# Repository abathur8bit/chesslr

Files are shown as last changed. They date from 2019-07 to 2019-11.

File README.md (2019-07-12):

# ChessLR
Electronic chess board project <https://www.8bitcoder.com/chesslr>

ChessLR is will be an chess e-Board and Chess Computer that can sense and record the movement of chess pieces. 

# Features

- Record games between two players.
- Play against a computer, and record the game.
- Recorded games can be downloaded. 
- Moves by the computer are indicated on the board using LEDs.
- Shows when you make a move that isn't legal.
- Setup any board position.

# How it works
There will be sensors under the board, as well as on the pieces. In the current design, reed switches will be under each square and magnets under the pieces. Reed switches are sensitive to magnetic fields that the magnets generate, and will activate when a piece is over it. This doesn't allow for piece identification, so it doens't know if a knight or a queen is over the square. By using a little bit of clever software, it should be fairly easy to keep track of what piece is where, and what piece moved. 

# Hardware
As the project evolves, the schematics will be updated. At present the board will be utilizing:

- Raspberry Pi for control logic and chess engine.
- LEDs for each square.
- Reed switches to sense pieces.
- Magnets under the pieces.
- MCP23017 I2C port expander to allow 64 inputs, and 64 outputs.

# Software
The driver for the board will be written in Java and meant to be run on a Raspberry Pi. It will utilize read reed switch state information, turn LEDs on and off, and talk with the chess engine. Software will also need to implement chess game logic, such as if a move is legal. I was surprised to learn that a chess engine doesn't acutally do that.

[Stockfish](https://stockfishchess.org) is the chess engine of choise. It's an open source chess engine written in C. It communicates via the Universal Chess Interface (UCI). ChessLR will send moves to Stockfish and when Stockfish sends it move back, the move will be indicated on the chess board via the LEDs.

# Resources
[PI4J](https://pi4j.com/1.2/index.html) Java I/O library for Raspberry PI.

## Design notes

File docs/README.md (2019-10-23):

Contains any reference material used for the project. This includes anything related to ChessLR game or electronics of the board itself. 

# FEN, PGN, EAN
https://en.wikipedia.org/wiki/Algebraic_notation_(chess)
https://en.wikipedia.org/wiki/Portable_Game_Notation

# Maven repository JitPack
<https://jitpack.io/private#subscribe>

Createa a maven repository based on github release.

# ChessLib
What I was trying to do with ChessBoard <https://github.com/bhlangonijr/chesslib>

# Board
```
   a  b  c  d  e  f  g  h
8  00 01 02 03 04 05 06 07  8
7  08 09 10 11 12 13 14 15  7
6  16 17 18 19 20 21 22 23  6
5  24 25 26 27 28 29 30 31  5
4  32 33 34 35 36 37 38 39  4 
3  40 41 42 43 44 45 46 47  3 
2  48 49 50 51 52 53 54 55  2 
1  56 57 58 59 60 61 62 63  1
   a  b  c  d  e  f  g  h
```

# Wait for move logic table
Table shows how many pieces are expected to be picked up and put down for each situation. This handles computer moves,
takebacks, and captures.

```
TAKEBACK    CAPTURE     UP  DOWN
Y           Y           1   2
Y           N           1   1
N           Y           2   1
N           N           1   1
```
  
# Wiring Notes #

Long headers are good to have something plugin at top, and do a bunch of wire wrapping on the bottom.

Each row from chess board will have 1 blue wire, the rest grey, to show direction it should face. Perhaps a blue wire for the first reed and a blue for the first LED.

# Running remotely

lee@titan: $ ssh pi@botfly
pi@fireant:~ $ cd chesslr
pi@fireant:~/chesslr $ export DISPLAY=:0
pi@fireant:~/chesslr $ java -cp chesslr-A.1-jar-with-dependencies.jar com.axorion.chesslr.ChessLR

# USB-C
USB-C Breakout board <https://www.adafruit.com/product/4090>
USB Micro B <https://www.adafruit.com/product/1833>

USB-C <http://ww1.microchip.com/downloads/en/appnotes/00001953a.pdf>
https://electronics.stackexchange.com/questions/323128/wiring-diagram-for-usb-c-to-usb-a-cable

# MCP23017

Pin layout

```
          +----- -----+
GPB0 <--> |*1   -   28| <--> GPA7
GPB1 <--> |2        27| <--> GPA6
GPB2 <--> |3        26| <--> GPA5
GPB3 <--> |4    M   25| <--> GPA4
GPB4 <--> |5    C   24| <--> GPA3
GPB5 <--> |6    P   23| <--> GPA2
GPB6 <--> |7    2   22| <--> GPA1
GPB7 <--> |8    3   21| <--> GPA0
 VDD ---> |9    0   20| ---> INTA
 VSS ---> |10   1   19| ---> INTB
  NC ---- |11   7   18| ---> RESET
 SCL ---> |12       17| <--- A2
 SDA <--> |13       16| <--- A1
  NC ---- |14       15| <--- A0
          +-----------+
```

# Misc
Restart X windows:

    sudo systemctl restart display-manager
    
Autorun script when X starts:

Putting following in `$HOME/.config/autostart/.desktop` and set `chmod +x`:

    [Desktop Entry]
    Type=Application
    Exec="/home/pi/bin/rot.sh"
    Hidden=false
    NoDisplay=false
    X-GNOME-Autostart-enabled=true
    Name=Startup Script 

# Power consumption
Display pulls between 450 and 470mA.
Typically, the model B uses between 700-1000mA
PI Hardware details <https://www.raspberrypi.org/documentation/hardware/raspberrypi/README.md>

# Display off
xset dpms force off

# Display rotation
Normal rotation is power cord at the bottom when it is plugged into the display board.

    pi@fireant:~ $ sudo apt-get install xinput
    pi@fireant:~ $ xinput --list
    ⎡ Virtual core pointer                    	id=2	[master pointer  (3)]
    ⎜   ↳ Virtual core XTEST pointer              	id=4	[slave  pointer  (2)]
    ⎜   ↳   Mini Keyboard                         	id=7	[slave  pointer  (2)]
    ⎜   ↳ FT5406 memory based driver              	id=8	[slave  pointer  (2)]
    ⎣ Virtual core keyboard                   	id=3	[master keyboard (2)]
        ↳ Virtual core XTEST keyboard             	id=5	[slave  keyboard (3)]
        ↳   Mini Keyboard                         	id=6	[slave  keyboard (3)]

## Fireant 90 degree rotation 
Power cord will be on the right side
 
    sudo vim /boot/config.txt

Add to top 

    display_rotate=1

Then run the following. `export` is only needed if you are ssh'ed in:

    export DISPLAY=:0
    xinput set-prop 'FT5406 memory based driver' 'Evdev Axes Swap' 1
    xinput --set-prop 'FT5406 memory based driver' 'Evdev Axis Inversion' 0 1
    
## Fireant 270 degree rotation
Power cord will be on the left side

    sudo vim /boot/config.txt

Add to top

    display_rotate=3

Then run the following. `export` is only needed if you are ssh'ed in:

    export DISPLAY=:0
    xinput set-prop 'FT5406 memory based driver' 'Evdev Axes Swap' 1
    xinput --set-prop 'FT5406 memory based driver' 'Evdev Axis Inversion' 1 0

## Other docs
<https://www.raspberrypi.org/documentation/hardware/display/>

Doesn't work on older Raspbain.

display_lcd_rotate=x, where x can be one of the folllowing:

    0	no rotation
    1	rotate 90 degrees clockwise
    2	rotate 180 degrees clockwise
    3	rotate 270 degrees clockwise
    0x10000	horizontal flip
    0x20000	vertical flip

    display_rotate=0 Normal
    display_rotate=1 90 degrees (power at right)
    display_rotate=2 180 degrees
    NOTE: You can rotate both the image and touch interface 180º by entering lcd_rotate=2 instead
    display_rotate=3 270 degrees
    display_rotate=0x10000 horizontal flip
    display_rotate=0x20000 vertical flip

## Older version of Raspbian (fireant)
lcd_rotate only works with 0 and 2. 2 is flipped 180 degrees (power at the top).

If you have the lcd_rotate=2 the power cord is at the top of the display. If you don't have it, the power cord is at the bottom of the display.

No present   power cord is at bottom
lcd_rotate=0 power cord is at bottom
lcd_rotate=1 power cord is at bottom
lcd_rotate=2 power cord is at top
lcd_rotate=3 power cord is at bottom

    sudo vim /boot/config.txt
    
    # screen totation added by me
    #lcd_rotate=2
    #display_rotate=1

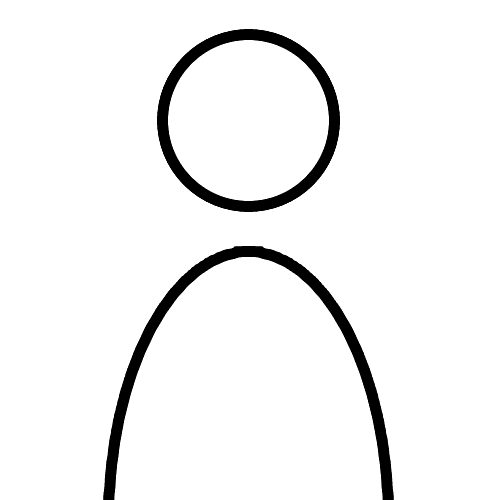
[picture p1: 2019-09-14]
src/main/java/img/button-onePlayerWhite.png

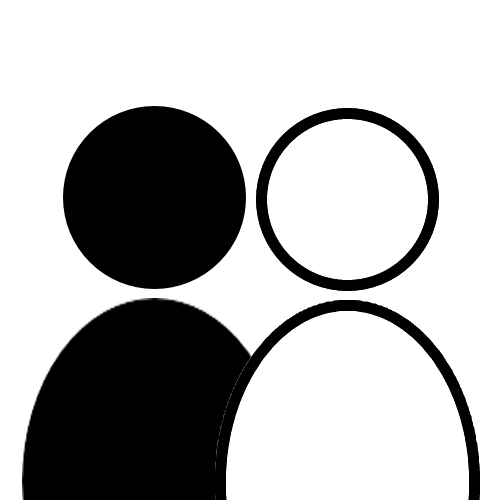
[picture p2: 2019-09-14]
src/main/java/img/button-twoPlayer.png

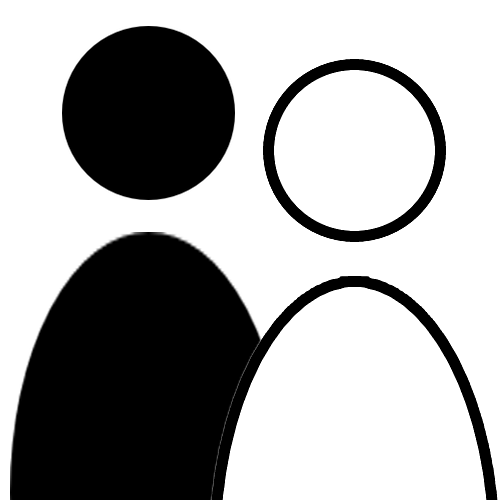
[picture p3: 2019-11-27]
src/main/java/img/button-twoPlayerWhite.png

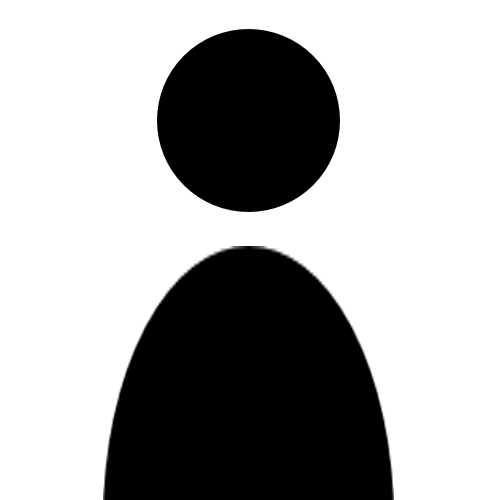
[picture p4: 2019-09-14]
src/main/java/img/button-onePlayerBlack.png

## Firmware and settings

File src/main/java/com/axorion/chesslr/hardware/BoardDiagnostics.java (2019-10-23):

package com.axorion.chesslr.hardware;

import com.axorion.chess.ChessBoard;
import com.pi4j.gpio.extension.mcp.MCP23017GpioProvider;
import com.pi4j.gpio.extension.mcp.MCP23017Pin;
import com.pi4j.io.gpio.*;
import com.pi4j.io.gpio.event.GpioPinListenerDigital;
import com.pi4j.io.i2c.I2CBus;
import com.pi4j.io.i2c.I2CFactory;

import java.io.IOException;

public class BoardDiagnostics implements PieceListener {
    class RowProvider {
        int bus,address;
        MCP23017GpioProvider gpioProvider;
        GpioPinDigitalOutput[] outputPins;
        GpioPinDigitalInput[] inputPins;

        Pin[] inputPinNames = {
                MCP23017Pin.GPIO_A0,
                MCP23017Pin.GPIO_A1,
                MCP23017Pin.GPIO_A2,
                MCP23017Pin.GPIO_A3,
                MCP23017Pin.GPIO_A4,
                MCP23017Pin.GPIO_A5,
                MCP23017Pin.GPIO_A6,
                MCP23017Pin.GPIO_A7,
        };
        Pin[] outputPinNames = {
                MCP23017Pin.GPIO_B7,
                MCP23017Pin.GPIO_B6,
                MCP23017Pin.GPIO_B5,
                MCP23017Pin.GPIO_B4,
                MCP23017Pin.GPIO_B3,
                MCP23017Pin.GPIO_B2,
                MCP23017Pin.GPIO_B1,
                MCP23017Pin.GPIO_B0,
        };
        PieceListener listener;

        public RowProvider(int bus,int address,PieceListener listener) throws Exception {
            this.bus = bus;
            this.address = address;
            this.listener = listener;

            gpioProvider = new MCP23017GpioProvider(bus,address);
            outputPins = new GpioPinDigitalOutput[BANK_SIZE];
            inputPins = new GpioPinDigitalInput[BANK_SIZE];

            //output
            for(int i=0; i<BANK_SIZE; i++) {
                String name = String.format("OUTPUT %02X - %s",address,outputPinNames[i].toString());
                System.out.printf("pin %02d name [%s]\n",i,name);
                outputPins[i] = gpio.provisionDigitalOutputPin(gpioProvider,outputPinNames[i],name,PinState.LOW);
            }
            //input
            for(int i=0; i<BANK_SIZE; ++i) {
                String name = String.format("INPUT %02X - %s",address,inputPinNames[i].toString());
                System.out.printf("pin %02d name [%s]\n",i,name);
                inputPins[i] = gpio.provisionDigitalInputPin(gpioProvider,inputPinNames[i],name,PinPullResistance.PULL_UP);
            }

            gpio.addListener((GpioPinListenerDigital)event -> {
                    final PinState state = event.getState();
                    final Pin pin = event.getPin().getPin();
                    final int pinIndex = findPinIndex(pin,inputPinNames);
                    final int boardIndex = (address-BASE_ADDRESS)*8+pinIndex;

                    System.out.printf("Handling event [%s] state [%s] for pin index [%d] board index [%d]\n",event.getPin().getName(),state,pinIndex,boardIndex);

                    if(listener != null) {
                        if(stateIsDown(state))
                            listener.pieceDown(boardIndex);
                        else
                            listener.pieceUp(boardIndex);
                    }
                },inputPins);
        }

        public void setState(boolean state,int index) {
            gpio.setState(state,outputPins[index]);
        }
    }

    final int BUS = I2CBus.BUS_1;
    static final int BASE_ADDRESS = 0x20;
    static final int BANK_SIZE = 8;
    static final int NUM_ROWS = 8;
    static final int NUM_COLS = 8;

    ChessBoard chessBoard;
    GpioController gpio;
    BoardController chessBoardController;
    RowProvider[] providers = new RowProvider[NUM_ROWS];

    public static void main(String[] args) throws Exception {
        BoardDiagnostics diag = new BoardDiagnostics();
//        diag.fullBoardTest();
//        diag.singleRowTest();
        diag.multiRowTest();
    }


    public BoardDiagnostics() throws Exception {
    }

    class MyListener implements PieceListener {
        RowProvider provider;

        @Override
        public void pieceUp(int boardIndex) {
            showRow(provider.outputPins,provider.inputPins);
        }

        @Override
        public void pieceDown(int boardIndex) {
            showRow(provider.outputPins,provider.inputPins);
        }
    }

    class MultiListener implements PieceListener {
        RowProvider[] providers;

        @Override
        public void pieceUp(int boardIndex) {
            showAll(providers);
        }

        @Override
        public void pieceDown(int boardIndex) {
            showAll(providers);
        }
    }
    public void singleRowTest() throws Exception {
        int address = BASE_ADDRESS+7;

        gpio = GpioFactory.getInstance();
        MyListener listener = new MyListener();
        RowProvider provider = new RowProvider(BUS,address,listener);
        listener.provider = provider;

        System.out.println("Ready to look for state changes");
        showRow(provider.outputPins,provider.inputPins);

        while(true) {

        }
    }

    public void multiRowTest() throws Exception {
        int address = BASE_ADDRESS;
        MultiListener listener = new MultiListener();

        gpio = GpioFactory.getInstance();
        for(int i = 0; i < NUM_ROWS; i++) {
            providers[i] = new RowProvider(BUS,address+i,listener);
        }

        listener.providers = providers;

        System.out.println("Ready to look for state changes");
        showAll(providers);
        while(true) {

        }
    }

    public int findPinIndex(Pin p,Pin[] pins) {
        for(int i=0; i<pins.length; ++i) {
            if(pins[i].equals(p))
                return i;
        }
        return -1;
    }

    public boolean stateIsDown(PinState state) {
        return state == PinState.HIGH ? false:true;
    }


    public void showAll(RowProvider[] providers) {
        for(RowProvider p : providers) {
            showRow(p.outputPins,p.inputPins);
        }
    }

    public void showRow(GpioPinDigitalOutput[] outputPins,GpioPinDigitalInput[] inputPins) {
        for(int i=0; i<BANK_SIZE; i++) {
            System.out.printf("%c ",stateIsDown(inputPins[i].getState()) ? 'X':'O');
            gpio.setState(stateIsDown(inputPins[i].getState()),outputPins[i]);
        }
        System.out.printf("\n");
    }

    public void fullBoardTest() throws Exception {
        chessBoard = new ChessBoard();
        gpio = GpioFactory.getInstance();
        initHardware();
        showBoard();
    }
    private void initHardware() throws IOException, I2CFactory.UnsupportedBusNumberException {
        final int bus = I2CBus.BUS_1;

        chessBoardController = new BoardController(gpio,bus);
        chessBoardController.addListener(this);
    }

    @Override
    public void pieceUp(int boardIndex) {
        show("UP  ",boardIndex);
    }

    @Override
    public void pieceDown(int boardIndex) {
        show("DOWN",boardIndex);
    }

    public void show(String msg,int boardIndex) {
        System.out.println(msg+" "+chessBoard.indexToBoard(boardIndex)+" "+boardIndex);
        showBoard();
    }

    public void showBoard() {
        for(int i = 0; i < 64; i++) {
            if(i>0 && i%8==0)
                System.out.println("");
            System.out.printf("%c ",chessBoardController.hasPiece(i) ? 'X':'O');
            chessBoardController.led(i,false);
//            chessBoardController.led(i,chessBoardController.hasPiece(i));
        }
        System.out.printf("\n");
    }
}

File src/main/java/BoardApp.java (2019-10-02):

/* *****************************************************************************
 * Copyright 2019 Lee Patterson <https://8BitCoder.com> <https://github.com/abathur8bit>
 *
 * You may use and modify at will. Please credit me in the source.
 *
 * Licensed under the Apache License, Version 2.0 (the "License");
 * you may not use this file except in compliance with the License.
 * You may obtain a copy of the License at
 *
 *   http://www.apache.org/licenses/LICENSE-2.0
 *
 * Unless required by applicable law or agreed to in writing, software
 * distributed under the License is distributed on an "AS IS" BASIS,
 * WITHOUT WARRANTIES OR CONDITIONS OF ANY KIND, either express or implied.
 * See the License for the specific language governing permissions and
 * limitations under the License.
 * ******************************************************************************/

import com.axorion.chess.ChessBoard;
import com.axorion.chesslr.hardware.LEDController3x3;
import com.axorion.chesslr.hardware.ReedController3x3;
import com.pi4j.io.gpio.GpioController;
import com.pi4j.io.gpio.GpioFactory;
import com.pi4j.io.i2c.I2CBus;
import com.pi4j.io.i2c.I2CFactory;
import oled.Font;
import oled.OLEDDisplay;

import java.io.IOException;

public class BoardApp {
    ChessBoard gameBoard;
    final GpioController gpio = GpioFactory.getInstance();
    LEDController3x3 ledController;
    ReedController3x3 reedController;
    OLEDDisplay display;
    int gamePieceSelected=0;
    int gamePieceCaptured=0;

    public static void main(String[] args) throws Exception {
        BoardApp app = new BoardApp();
        app.startup();
        app.play();
    }


    public BoardApp() throws I2CFactory.UnsupportedBusNumberException, IOException {
        gameBoard = new ChessBoard();
        ledController = new LEDController3x3(gpio,I2CBus.BUS_1);
        reedController = new ReedController3x3(gpio,I2CBus.BUS_1);
//        reedController.addListener(new GpioPinListenerDigital() {
//            public void handleGpioPinDigitalStateChangeEvent(GpioPinDigitalStateChangeEvent event) {
//                boolean state = event.getState() == PinState.HIGH ? false:true;
//                int ledIndex = reedController.findPinIndex(event.getPin().getPin());
//
////                System.out.println("application gpio pin state change: " + event.getPin() + " = " + event.getState() + " led="+ledIndex);
//
//                if(state) {
//                    pieceDown(ledIndex);
//                } else {
//                    pieceUp(ledIndex);
//                }
//
////                if(state) {
////                    display.clear();
////                    showBoard();
////                    final int x=9;
////                    textxy("B00:00:00",x,0);
////                    textxy("W00:00:00",x,1);
////                    textxy("led="+ledIndex,x,7);
////                    updateDisplay();
////                }
//
//            }
//        });
        display = new OLEDDisplay(I2CBus.BUS_1,0x3D);

    }

    public void blink(int count, long delay, int ledIndex) {
        try {
            for(int i = 0; i < count; i++) {
                ledController.led(ledIndex,true);
                Thread.sleep(delay);
                ledController.led(ledIndex,false);
                Thread.sleep(delay);
            }
        } catch(InterruptedException e) {
            ledController.led(ledIndex,false);
        }
    }

    /**
     * Piece was lifted off the board.
     *
     * @param index location piece was picked up from.
     */
    public void pieceUp(int index) {
        int boardIndex = mapToBoard(index);
        gamePieceSelected = boardIndex;
        System.out.format("Piece at [%d] [%s] was selected\n",index,gameBoard.indexToBoard(boardIndex));
        blink(1,100,index);
        display.clear();
        showBoard();
        updateDisplay();
    }

    /**
     * Piece was put back onto the board at the given index.
     *
     * @param index location piece was dropped.
     */
    public void pieceDown(int index) {
        int boardIndex = mapToBoard(index);
        String playersMove = gameBoard.indexToBoard(gamePieceSelected)+gameBoard.indexToBoard(boardIndex);
        gameBoard.move(playersMove);
        gamePieceSelected = -1;
        System.out.format("Piece dropped at [%d] [%s] move=[%s]\n",index,gameBoard.indexToBoard(boardIndex),playersMove);
        showBoard();
        updateDisplay();
        blink(2,100,index);
    }

    public int mapToBoard(int index) {
        int[] map = {56,57,58,48,49,50,40,41,42};
        return map[index];
    }
    public void showBoard() {
        StringBuilder builder = new StringBuilder();
        int y=0,x=0;
        int index=0;
        int w= Font.FONT_5X8.getOuterWidth()+1;
        int h=8;
        int tx;
        int ty;

        for(ty=0; ty<8; ty++) {
            builder.delete(0,8);
            for(tx=0; tx<8; tx++) {
                x=tx*w;
                y=ty*h;
                if(gamePieceSelected == index) {
                    display.clearRect(x,y,w,h,true);
                    display.drawChar(gameBoard.pieceAt(index++),Font.FONT_5X8,x,y,false);
                } else {
                    display.clearRect(x,y,w,h,false);
                    display.drawChar(gameBoard.pieceAt(index++),Font.FONT_5X8,x,y,true);
                }
            }
        }
    }

    public void showBoardComponents() throws IOException {
        display.clear();
        showBoard();
        final int x=9;
        int y=0;
        textxy("B00:00:00",x,y++);
        textxy("W00:00:00",x,y++);
        textxy("1 b3  d5",x,y++);
        textxy("2 O-O-O",x,y++);
        textxy("2.. O-O-O",x,y++);
        textxy("3 Nf3 Nf6",x,y++);
        textxy("4 g3  Bc5",x,y++);
        textxy("5 Bg2 O-O",x,y++);
        textxy("6 *",x,y++);
    }

    public void drawRect(OLEDDisplay display,int xpos,int ypos,int width,int height,boolean on) {
        int y=ypos;
        int x=xpos;
        for(x=xpos; x<xpos+width-1; ++x) {
            display.setPixel(x,y,on);
        }
        y=ypos+height-1;
        for(x=xpos; x<xpos+width-1; ++x) {
            display.setPixel(x,y,on);
        }

        x=xpos;
        for(y=ypos; y<ypos+height-1; ++y) {
            display.setPixel(x,y,on);
        }
        x=xpos+width-1;
        for(y=ypos; y<ypos+height-1; ++y) {
            display.setPixel(x,y,on);
        }
    }

    public void textxy(String s,int tx,int ty) {
        int w= Font.FONT_5X8.getOuterWidth()+1;
        int h=8;
        int x=tx*w;
        int y=ty*h;
        for(int i=0; i<s.length(); i++) {
            display.drawChar(s.charAt(i),Font.FONT_5X8,(tx+i)*w,ty*h,true);
        }
    }

    public void updateDisplay() {
        try {
            display.update();
        } catch(IOException ex) {
            //do nothing
        }
    }
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

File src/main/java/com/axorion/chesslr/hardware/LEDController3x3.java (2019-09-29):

/* *****************************************************************************
 * Copyright 2019 Lee Patterson <https://8BitCoder.com> <https://github.com/abathur8bit>
 *
 * You may use and modify at will. Please credit me in the source.
 *
 * Licensed under the Apache License, Version 2.0 (the "License");
 * you may not use this file except in compliance with the License.
 * You may obtain a copy of the License at
 *
 *   http://www.apache.org/licenses/LICENSE-2.0
 *
 * Unless required by applicable law or agreed to in writing, software
 * distributed under the License is distributed on an "AS IS" BASIS,
 * WITHOUT WARRANTIES OR CONDITIONS OF ANY KIND, either express or implied.
 * See the License for the specific language governing permissions and
 * limitations under the License.
 * ******************************************************************************/

package com.axorion.chesslr.hardware;

import com.pi4j.gpio.extension.mcp.MCP23017GpioProvider;
import com.pi4j.gpio.extension.mcp.MCP23017Pin;
import com.pi4j.io.gpio.GpioController;
import com.pi4j.io.gpio.GpioPinDigitalOutput;
import com.pi4j.io.gpio.Pin;
import com.pi4j.io.gpio.PinState;
import com.pi4j.io.i2c.I2CFactory;

import java.io.IOException;

/**
 * Class for manipulating the LEDs on the chess board. 8x8 for a total of
 * 64 LEDs controlled. You can turn them on/off via index (0-63) or x,y position.
 *
 * Uses MCP23017 ports 0x20-0x23 (000-011 binary).
 *
 *           +----- -----+
 * GPB0 <--> |*1   -   28| <--> GPA7
 * GPB1 <--> |2        27| <--> GPA6
 * GPB2 <--> |3        26| <--> GPA5
 * GPB3 <--> |4    M   25| <--> GPA4
 * GPB4 <--> |5    C   24| <--> GPA3
 * GPB5 <--> |6    P   23| <--> GPA2
 * GPB6 <--> |7    2   22| <--> GPA1
 * GPB7 <--> |8    3   21| <--> GPA0
 *  VDD ---> |9    0   20| ---> INTA
 *  VSS ---> |10   1   19| ---> INTB
 *   NC ---- |11   7   18| ---> RESET
 *  SCL ---> |12       17| <--- A2
 *  SDA <--> |13       16| <--- A1
 *   NC ---- |14       15| <--- A0
 *           +-----------+
 */
public class LEDController3x3 implements LEDController {
    class FadeThread implements Runnable {
        boolean running = true;
        boolean onState = false;
        GpioPinDigitalOutput led;
        long timer=0;
        static final long DELAY=10;
        int timeOn = 500000;
        int timeOff=500000;
        public FadeThread(GpioPinDigitalOutput led) {
            this.led = led;
            timer = System.currentTimeMillis()+DELAY;
        }
        public void run() {
            try {
                milli();
            } catch(InterruptedException e) {
                //do nothing
            }
        }

        public void milli() throws InterruptedException {
            long onTime=0;
            long dir=1;
            long delay=50;
            long timer=System.currentTimeMillis()+delay;
            while(running) {
                cycle(onTime);
                if(System.currentTimeMillis() > timer) {
                    timer = System.currentTimeMillis()+delay;
                    onTime+=dir;
                    if(onTime==20 || onTime==0) {
                        dir *= -1;
                    }
                }
            }
        }
        public void cycle(long onTime) throws InterruptedException {
            gpio.setState(true,out);
//            led.setState(PinState.HIGH);
            Thread.sleep(onTime);
//            led.setState(PinState.LOW);
            gpio.setState(false,out);
            Thread.sleep(20-onTime);
        }
        public void micro() throws InterruptedException {
            while(running) {
//                PinState state = onState ? PinState.HIGH:PinState.LOW;
                //turn on for 10ms
                timer = System.currentTimeMillis()+DELAY;
                led.setState(PinState.HIGH);
//                    Thread.sleep(timeOn);
                Thread.sleep(0,250000);
                led.setState(PinState.LOW);
//                    Thread.sleep(timeOff);
                Thread.sleep(1,750000);
            }

        }
    };


    FadeThread fadeThread;

    static final int BANK_SIZE = 16;
    static final int BASE_ADDRESS = 0x20;

    GpioController gpio;
    MCP23017GpioProvider provider;
    GpioPinDigitalOutput[] out = new GpioPinDigitalOutput[BANK_SIZE];

    int[] bankAddress = {
            BASE_ADDRESS+0,
            BASE_ADDRESS+1,
            BASE_ADDRESS+2,
            BASE_ADDRESS+3,
    };
    Pin[] pins = {
            MCP23017Pin.GPIO_A0,
            MCP23017Pin.GPIO_A1,
            MCP23017Pin.GPIO_A2,

            MCP23017Pin.GPIO_A3,
            MCP23017Pin.GPIO_A4,
            MCP23017Pin.GPIO_A5,

            MCP23017Pin.GPIO_A6,
            MCP23017Pin.GPIO_A7,
            MCP23017Pin.GPIO_B0,

            MCP23017Pin.GPIO_B1,
            MCP23017Pin.GPIO_B2,
            MCP23017Pin.GPIO_B3,
            MCP23017Pin.GPIO_B4,
            MCP23017Pin.GPIO_B5,
            MCP23017Pin.GPIO_B6,
            MCP23017Pin.GPIO_B7,
    };

    public LEDController3x3() {}
    public LEDController3x3(GpioController gpio,int bus) throws IOException, I2CFactory.UnsupportedBusNumberException {
        init(gpio,bus);
    }

    public void init(GpioController gpio,int bus) throws IOException, I2CFactory.UnsupportedBusNumberException {
        this.gpio = gpio;
        provider = new MCP23017GpioProvider(bus,BASE_ADDRESS);
        initBank(0);

    }

    protected void initBank(int bank) {
        for(int i=0; i<16; ++i) {
            out[i] = gpio.provisionDigitalOutputPin(provider,pins[i],pins[i].toString(),PinState.LOW);
        }
    }

    /**
     * Turn the specified LED on or off.
     *
     * @param led LED index number.
     * @param on true to turn on, false to turn off.
     */
    public void led(int led,boolean on) {
        int bank = calcBank(led);
        int bankLed = calcBankLed(bank,led);
        set(bank,bankLed,on);
    }

    public void blink(int led) {
        int bank = calcBank(led);
        int bankLed = calcBankLed(bank,led);
        out[led].blink(200);
    }
    public void blink(int led,long duration) {
        int bank = calcBank(led);
        int bankLed = calcBankLed(bank,led);
        out[led].blink(200,duration);
    }


    public void fade(int led) {
        int bank = calcBank(led);
        int bankLed = calcBankLed(bank,led);
        fadeThread = new FadeThread(out[0]);
        new Thread(fadeThread).start();
    }

    protected void set(int bank,int led,boolean on) {
        PinState state = on?PinState.HIGH:PinState.LOW;
        out[led].setState(state);
    }

    public boolean isOn(int led) {
        int bank = calcBank(led);
        int bankLed = calcBankLed(bank,led);
        return out[led].getState() == PinState.HIGH;
    }

    public int calcBank(int led) {
        return led/BANK_SIZE;
    }

    public int calcBankLed(int bank,int led) {
        return led-bank*BANK_SIZE;
    }
}

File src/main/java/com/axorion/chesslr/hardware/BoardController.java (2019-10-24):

/* *****************************************************************************
 * Copyright 2019 Lee Patterson <https://8BitCoder.com> <https://github.com/abathur8bit>
 *
 * Created 2019-09-05
 *
 * You may use and modify at will. Please credit me in the source.
 *
 * Licensed under the Apache License, Version 2.0 (the "License");
 * you may not use this file except in compliance with the License.
 * You may obtain a copy of the License at
 *
 *   http://www.apache.org/licenses/LICENSE-2.0
 *
 * Unless required by applicable law or agreed to in writing, software
 * distributed under the License is distributed on an "AS IS" BASIS,
 * WITHOUT WARRANTIES OR CONDITIONS OF ANY KIND, either express or implied.
 * See the License for the specific language governing permissions and
 * limitations under the License.
 * ******************************************************************************/

package com.axorion.chesslr.hardware;

import com.pi4j.io.gpio.GpioController;
import com.pi4j.io.gpio.Pin;
import com.pi4j.io.gpio.PinState;
import com.pi4j.io.i2c.I2CBus;
import com.pi4j.io.i2c.I2CFactory;

import java.io.IOException;
import java.util.ArrayList;

/**
 * Controls all the chess board hardware. User should assume an 8x8 board.
 * Controller takes care of mapping a 3x3 proto board to a full 8x8
 * coords and visa versa.
 *
 * - LED on and flash means waiting for a piece to be put down.
 * - LED off and flashing means wait for piece to be removed.
 *
 * <pre>
 *    a  b  c  d  e  f  g  h
 * 8  00 01 02 03 04 05 06 07  8
 * 7  08 09 10 11 12 13 14 15  7
 * 6  16 17 18 19 20 21 22 23  6
 * 5  24 25 26 27 28 29 30 31  5
 * 4  32 33 34 35 36 37 38 39  4
 * 3  40 41 42 43 44 45 46 47  3
 * 2  48 49 50 51 52 53 54 55  2
 * 1  56 57 58 59 60 61 62 63  1
 *    a  b  c  d  e  f  g  h
 * </pre>
 */
public class BoardController implements PieceListener, ProviderListener {

    final int BUS = I2CBus.BUS_1;
    static final int BASE_ADDRESS = 0x20;
    static final int BANK_SIZE = 8;
    static final int NUM_ROWS = 8;
    static final int NUM_COLS = 8;

    GpioController gpio;
    LEDController ledController;
    InputController reedController;
    ArrayList<PieceListener> pieceListeners = new ArrayList<PieceListener>();

    FlashThread flashThread;

    int[] boardToPinMap3x3 = {
            0,1,2,0,0,0,0,0,
            3,4,5,0,0,0,0,0,
            6,7,8,0,0,0,0,0,
            0,0,0,0,0,0,0,0,
            0,0,0,0,0,0,0,0,
            0,0,0,0,0,0,0,0,
            0,0,0,0,0,0,0,0,
            0,0,0,0,0,0,0,0
    };

    int[] pinToBoardMap3x3 = {
            0,1,2,
            8,9,10,
            16,17,18}; //top left

    /**
     * Normally the reeds go from 0 through 63 in order. But if you wired them in the
     * wrong order, this index will be used to map them from the pin index to the board
     * index.
     */
    int[] remap = {
             0, 1, 2, 3, 4, 5, 6, 7,
             8, 9,10,11,12,13,14,15,
            16,17,18,19,20,21,22,23,
            24,25,26,27,28,29,30,31,
            32,33,34,36,35,37,38,39,
            40,41,42,43,44,45,46,47,
            48,49,50,51,52,53,54,55,
            56,57,58,59,60,61,62,63
    };


    RowProvider[] rowProviders = new RowProvider[NUM_ROWS];

    class BoardLEDController implements LEDController {
        @Override
        public void led(int boardIndex,boolean on) {
            int row = boardIndex/8;
            int col = boardIndex-row*8;
            RowProvider provider = rowProviders[row];
            provider.setState(on,col);
        }

        @Override
        public boolean isOn(int boardIndex) {
            int row = boardIndex/8;
            int col = boardIndex-row*8;
            RowProvider provider = rowProviders[row];
            return provider.outputPins[col].getState().isHigh();
        }
    }

    class BoardInputController implements InputController {
        @Override
        public void addListener(PieceListener listener) {
            pieceListeners.add(listener);
        }

        @Override
        public int findPinIndex(Pin pin) {
            return 0;   //not used
        }

        @Override
        /** Returns if the state means a piece is down or not.
         *
         * @param state State to check.
         * @return true if piece is detected, false otherwise.
         */
        public boolean stateIsDown(PinState state) {
            return state == PinState.HIGH ? false:true;
        }

        @Override
        public boolean isSet(int boardIndex) {
            boardIndex = remap[boardIndex];     //to handle reed switches that are wired incorrectly
            int row = boardIndex/8;
            int col = boardIndex-row*8;
            RowProvider provider = rowProviders[row];
            return provider.inputPins[col].getState().isLow();
        }
    }

    public BoardController(LEDController led,InputController input) throws IOException, I2CFactory.UnsupportedBusNumberException {
        this.ledController = led;
        this.reedController = input;
        flashThread = new FlashThread(ledController);
        flashThread.start();
    }

    public BoardController(GpioController gpio,int bus) throws IOException, I2CFactory.UnsupportedBusNumberException {
        this.gpio = gpio;
        if(gpio == null) {
            // use simulated board
        } else {
            ledController = new BoardLEDController();
            reedController = new BoardInputController();
            for(int i = 0; i < NUM_ROWS; i++) {
                rowProviders[i] = new RowProvider(gpio,BUS,BASE_ADDRESS+i,this);
            }
        }
        flashThread = new FlashThread(ledController);
        flashThread.start();
    }

    public void flashOn(int ledIndex) {
        flashThread.addLed(ledIndex);
    }

    public void flashOff(int ledIndex) {
        flashThread.removeLed(ledIndex);
    }

    public InputController getInputController() {
        return reedController;
    }

    public LEDController getLedController() {
        return ledController;
    }

    public void led(int squareIndex,boolean on) {
        if(squareIndex == -1) {
            for(int i = 0; i < 64; i++) {
                ledController.led(i,on);
            }
        } else {
            ledController.led(squareIndex,on);
        }
    }

    /** Return if an LED is on at the specified index. */
    public boolean isLEDOn(int boardIndex) {
        return ledController.isOn(boardIndex);
    }

    /**
     * Return if a piece is down at the specified index.
     *
     * @param boardIndex Index to check.
     * @return true if there is a piece on the square, false otherwise.
     */
    public boolean hasPiece(int boardIndex) {
        return reedController.isSet(boardIndex);
    }

    public void addListener(PieceListener listener) {
        pieceListeners.add(listener);
    }
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

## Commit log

2019-04-13 Board drawing and simulated board drawing
2019-04-14 Board and interface are able to move pieces around and capture. Also make and deploy scripts to handle building App, EXE and copying to web site.
2019-06-17 Board now draws the squares itself instead of using an image
2019-06-17 Size is passed in, moving away from prototype magic numbers.
2019-07-04 Test for I2C port
    [proto01.fzz]
2019-07-05 Correction to the pin numbers
2019-07-07 3x3 prototype. Started controller classes for reed switches and LEDs that intended for final code.
    [proto01.fzz]
2019-08-07 Fixed the sim board position on app startup. Now is positioned to the right of the game board.
    [AppFrame.java]
2019-08-16 Now running ChessLR GUI on the RPi.
    [chesslr-mcp23017-boardlayout.fzz, multipower.fzz]
2019-08-16 Moved blink code into a thread so UI isn't effected, also won't delay seeing switch state changes.
    [AppFrame.java]
2019-08-18 added some docs, todos, preliminary images for buttons.
    [chesslr-mcp23017-boardlayout.fzz]
2019-08-29 Refactored controllers to get ready for transitioning to 8x8 board, but still be able to use 3x3 board for testing logic.
2019-08-29 Schematic for 3x3 interface board.
    [mcp-3x3.fzz]
2019-08-30 Using Reed switches in the schematic now to match the real hardware used.
    [mcp-3x3.fzz]
2019-09-05 Rewired hardware, so repointing pins to the correct location. Hardware now has pin 0 top left.
    [ChessLEDController.java, ChessReedController.java]
2019-09-05 Game now saves in from-to format ("b1c3") and PGN ("Nc3"). PGN not completely implemented.
    [chesslr-mcp23017-boardlayout.fzz, proto01.fzz]
2019-09-05 Created a board controller to move all hardware and pin mapping there so app can just work with board coordinates and deal with logical events instead of hardware events.
2019-09-05 Take back refactored, app now handles incorrect piece up or down when it's waiting for a specific move. Both LED flash and dialog is shown.
2019-09-10 New board tester for testing MCP boards, to ensure LED and inputs work. Removed init() from controller interfaces leaving that to the constructor
    [mcp-3x3.fzz]
2019-09-12 Finished up takeback logic. Now flashes to indicate that you need to replace a piece, and highlights on the display board what piece needs to be replaced.
    [AppFrame.java, BoardController.java]
2019-09-12 Reimplemented the simulated board. Game now runs on host machine and you can use the simulated board instead of the attached e-board. Let's me use a full 8x8 board.
2019-09-12 Make sim board a little easier to see when sensor is set to see a piece.
2019-09-12 Sim board is cleaner without the LEDs showing when they are off.
2019-09-12 Squares on display board are now highlighted for pieces that are picked up, and when a move is complete.
2019-09-12 Changed square colors for selected modes to be dark/light based on the color of the square to improve it's look. Added layout mode to show where pieces should be based on what is on chess board in me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
2019-09-14 Settings dialog created. Moved PGN notation and new game options to the settings dialog and out of the button bar of the game. Started playing with Chess Lib API to simplify keeping moves legal.
2019-09-14 Button images checked in. Player buttons now have images.
2019-09-15 Disable engine option added in one player game for testing purposes, so I can toggle it on and off. Small workaround for simboard clicking events.
    [AppFrame.java, SimBoard.java]
2019-09-23 Fixed move sequences to better handle takeback and capture logic.
    [AppFrame.java]
2019-09-29 Added LED test code that utilizes animated GIFs to set LED states. Using real 8x8 hardware for LEDs. Reeds still working on issue.
    [AppFrame.java, BoardApp.java, BoardController.java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]
2019-10-02 New LED and reed controller logic to handle the 8 different GPIO addresses.
2019-10-23 Updates to handle turning all LED's on and off at once.
2019-10-23 Fixed issue of wrong reed switches being read on e-board. Updates to the way castling works. Wait time for moves when you are not using hardware reduced to make play faster. Added board diagnostic pr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
    [mcp-3x3.fzz]
2019-10-24 Updated pin remapping so it works in board conrollers new structure
2019-10-24 Fixed selection and led when you piece up the opposite color first. Now both pieces will show as selected.
    [AppFrame.java]
2019-10-24 Changed wait for move logic to handle multiple moves. This handles the case of castling for player and computer. Also added additional debug logs for stockfish moves.
